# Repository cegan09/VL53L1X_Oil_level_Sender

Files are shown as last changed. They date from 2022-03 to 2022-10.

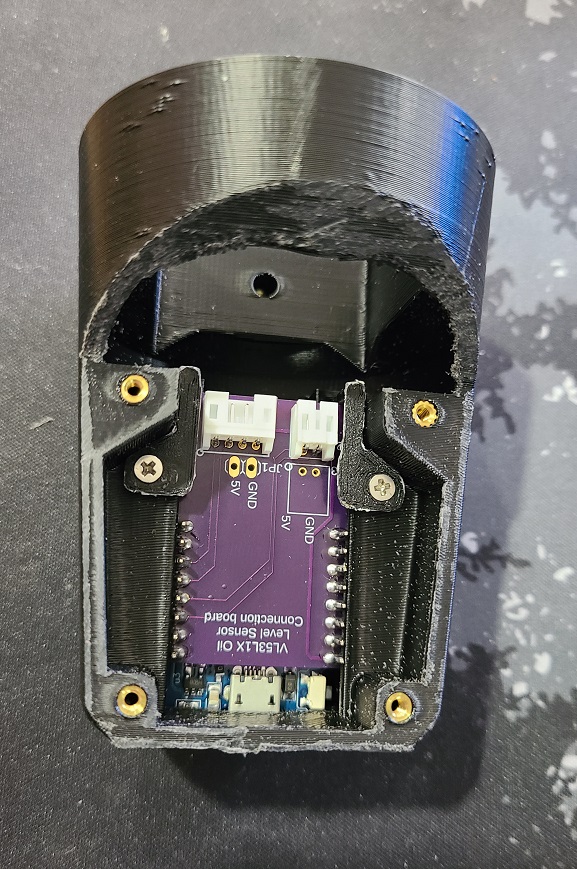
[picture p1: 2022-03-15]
pictures/Board Installed.jpg

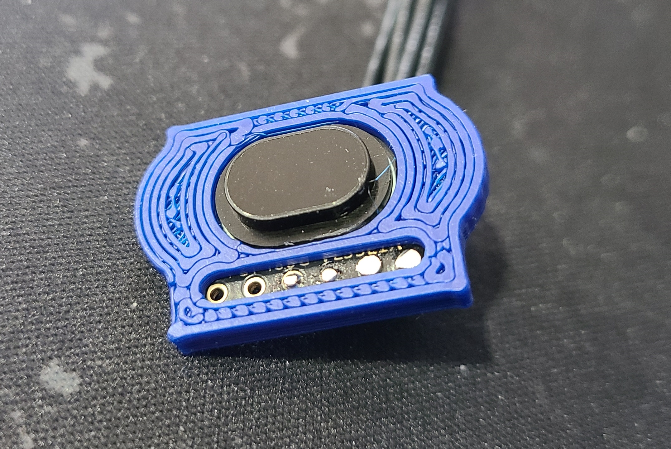
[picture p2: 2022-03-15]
pictures/Wire Test Fit.jpg

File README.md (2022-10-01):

# VL53L1X_Oil_level_Sender
DIY Home Heating Oil Level Sender

## Updates
Added configuration for ESPHome in addition to custom arduino code

## Open bugs
Occasionally I will see the device hang up. Logs show that the sensor reading is timing out. Rebooting the device works to correct this, but I haven't sorted the underlying cause yet. If you are using the ESPHome setup you can configure an automation to reboot the device when a reading of 0 comes through. 

## Warnings
This device probably voids some warrantees, will make your heating oil companies mad, and nullify your home insurance. Maybe, I'm not a lawyer. Just know that installing a DIY device on your heating oil tank probably will get some eyebrows raised if anything goes wrong. Get your tank inspected regularly, do not install if you are not comfortable doing it yourself. I am not responsible for anything that goes wrong on your end. 

There are commercial devices you can buy to perform the same function as this device that are certified and approved. If you have any hesitation to a DIY solution, go buy one of those instead. 

#### Safety
Heating oil tanks undergo some large pressures during filling and there are some safety items that you do not want to interfere with. 
1. Most commercial indoor basement tanks in North America use a whistle to tell the truck driver when to stop filling with oil. This device relies on there being no open air vents other than the single vent pipe that exists next to the fill pipe. This means your sensor needs to be sealed and air tight. This requires filling the plug that is used with potting or other appropriate epoxy. 
2. Leaks. Heating oil leaks are expensive to clean up and dangerous. Your sensor needs to be built into the correct plug, and then installed with the correct thread sealant and tightened appropriately. If you do not know how to do this, consult someone that does. 
3. Pressure. Heating oil tanks are rated to 5-7psi, which sounds low, but results in a huge force on the tank walls. Look up hoop stress if you want to know more. In a tank the size of your heating oil tank 5psi can exert hundreds of pounds of force on the shell of the tank. However, at the cap we're using, because the surface area is small, the forces on the actual device are small. If you keep the hole you drill in the plug small then potting compound or epoxy will have no problem with the forces that exist during filling. 
4. Electrical shorts and sparks. Home heating oil is thankfully not as volatile as other fuels, but you still absolutely do not want to be putting any kind of spark inside your tank. Any electrical device is a spark risk. Even if the sensor is running at 3.3v there are always surge risks from outside factors such as lightning strikes. This is why the design used here isolates and embeds all electronics in potting material. There should be no exposed path for any circuitry to be exposed to the atmosphere inside the tank. 

#### Device
With all those warnings out of the way, onto the device. Very simply this is nothing more than a Time of Flight distance sensor and a wifi connected microcontroller. The time of flight sensor measures the distance to the top of the oil level, and the micro controller does something with that data. In my case I'm simply pushing the distance off to a Node Red flow in its raw reading format. However, you can do all levels of data analysis on the microcontroller itself. ESP devices are more than capable of hosting a simple web page to display data. 

The oil level sender is effectively two parts. Part 1 is the sensor embedded in a standard off the shelf Black Iron plug. Part 2 is the microcontroller and housing. 

##### Parts List
Required:
1.	VL53L1X Sensor. There are several versions of the VL53 sensor, specifically this design uses the L1X version. Make sure you buy one with a cover. There are two common versions sold, part files are provided for each

Cover 1
Cover 2

2.	2” Black Iron Plug. These can be found at most hardware stores, once example:
https://www.homedepot.com/p/STZ-2-in-Black-Iron-Plug-310-P-2/202337741
3.	Isolation Plate. This can be made by hand, or ordered. The dxf file is included and can be sent to a service such as Send Cut Send. Alternately you can use it as a template to cut out by hand. Recommend the plate be made from regular or stainless steel, roughly 0.06” thick. 
4.	Sensor Spacer. STL files included to be printed or sent to a service. 
5.	ESP8266 Microcontroller. I use the D1 mini, but almost any version can be used, just make sure to check your wiring against the code pin definitions. 
6.	Wire. Recommend something between 26 and 22 gauge. 
7.	Potting material. The best option here is an electrically isolating potting material such as MG Chemicals - 832HD. Generic dispensing guns are available all over places like amazon. 

Optional:
1.	3d Printed enclosure. I’ve provided a few different STL files for different enclosures. You’re more than welcome to design your own or leave the microcontroller dangling on top of your tank if that’s your style. 
2.	D1 Mini Carrier board. This is the board I designed to clean up my installation. It’s certainly not required, but I have provided the board files if you want to send them to your favorite board house. Alternatively, they can be ordered straight from oshpark:
https://oshpark.com/shared_projects/pPlbGjjf
There is a BOM for this board provided in the documentation. 

##### Sensor and Plug
You should use a real metal plug bought from your local hardware store. Do not use plastic, do not 3d print something, go buy the right part, they only cost a couple dollars. In this plug drill a hole through the top that is roughly 1/4inch diameter. Feel free to do a better job centering the hole than I did.  



Prepping the sensor. First print out the spacer. This is used to make the carrier board sit flat on our isolation plate and keeps the soldered wires from shorting on the isolation plate. If the sensor cover did not come pre-installed fit it now, then test fit everything into the printed spacer. 

Sensor Test Fit

Next wire up the sensor. These can be run with or without the Interrupt and Shutdown pins. If you're trying to run multiple sensors these pins are not optional, but this device uses only one. It doesn't hurt to wire all pins and run them just in case, since you can't get at the sensor after potting. I have opted to only wire the SCL,SDA,3v3, and GND wires in these pictures. 

Sensor WIred

Fit the sensor into the spacer again and make sure the wire stubs sit recessed. Use a small file to take them down if required. You do NOT want these to touch and short out on the isolation plate. 

Wire Test Fit

If you are opting to make your own isolation plate, cut out the isolation plate. This really should be made from metal for its chemical resistance. The outer shape does not need to be perfect, but the cutout around the sensor should be a close fit. Take your time with a small file and get it close.

Isolation Plate

When your parts are ready, first glue the sensor into the spacer. I used a little CCA glue just to hold it in place until the potting compound sets. 

Sensor Glued in

The potting epoxy likes to seep through any open gap. It’s wise to seal up around the sensor before we install the plate into the plug. The best approach I’ve found is to use hot melt glue to seal the front of the sensor cover and make a dam around the spacer. These keeps the potting material from leaking onto the front of the sensor cover or dripping off the edge of the isolation plate. So first build up a ring of hot melt glue around the place where the sensor will be placed.

Glue Dam

Next place a small amount of potting epoxy on the isolation plate to seal between the plate and sensor spacer/PCB.

First Potting Layer

Place the sensor on the plate being careful not to get any potting material on the sensor cover. Then hold it in place and add hot melt glue to the front surface. This both holds the sensor in place and stops potting material from leaking out  around the cover. 

Sensor Dam

Add a thin layer of potting material to the dammed area. The goal is not to fill the whole area, just add enough to coat everything and allow it to seal up. 

First Light Potting Fill

Once the potting material is fully cured (minimum 12 hours), remove all the hot melt glue. 
Now we need to fully pot the sensor into the cap. First fully clean the metal plug. Often they are shipped with a thin layer of oil coating them to stop corrosion. You want to fully remove this from the inside so that the potting material and hot melt glue will stick. 

Pass the wiring through the cap, and populate the connectors. I strongly suggest testing this now before you pot everything and lose the ability to diagnose a miswired connector. 



Use more hot melt glue to hold the isolation plate into the cap and seal up the gap between the two. This will keep the potting material from leaking through and making a mess. 



Now it's time to inject the potting compound into the back of the sensor through the hole we drilled for wires. Take your time and inject the compound allowing it to flow and settle a little bit at a time. You want this cavity completely filled. Allow this to completely cure. 




Once everything is cured remove the hot melt glue we applied earlier. 

You can now optionally add a chemically resistant epoxy to the joint between the isolation plate and plug. This shouldn’t be strictly necessary, but it’s not a bad idea to add.  

You should now have your completed sensor plug assembly. 

##### Microcontroller and Enclosure
This part is flexible. You can follow my version, or you can really attach any microcontroller you prefer and enclose in any way you want. If you are using my design, I have a few options. I've designed this around an ESP8266 D1 Mini. The ESP32 is newer and fancier, but we really don't need the increased power of the newer device. You can hand wire everything, or you can order the cheap connection PCB I have designed and linked on oshpark. All this board does is make wiring the device easier, it's not necessary if you're comfortable hand wiring things. 

For enclosures I have three versions. Two are based around using my connector board, the other is just a bare shell that you can use for fitting your own wiring and microcontroller into. The two based around my design allow you to either expose the USB connector on the D1 mini or install a DC power jack.

For any of the enclosures I recommend printing in either PETG or ABS/ASA. I suggest minimum 3 shells, 4 is better to make sure there is enough material around the threaded inserts. I use brass heat set inserts for all fasteners. 

Wiring is straight forward. Whether you use my carrier board or wire it all by hand the connections are the same. If you do use my carrier board you can get away with only wiring up 3.3V, ground, SCL, and SDA, though adding the Shutdown and interrupt wires may let you write more complicated programs. If you do use my carrier board you have the option to wire power to a 2mm pitch JST connector, or just solder wires directly to the board at JP1. If you're exposing the USB connector then you can skip either of those as power will come from the USB. 

Carrier Board 1
Carrier Board 2
Board Installed

#### Installation
Installing the device is straightforward. You will first need to remove one of the extra plugs in the top of your tank. I recommend picking the one furthest from the fill pipe to avoid splashing when the tank is being filled. Before threading in the device, make sure to apply the appropriate pipe dope compound to the threads to make sure it seals and prevent the threads corroding. 

Thread the plug in by hand to make sure it does not cross thread, then tighten down fully. 

Make the connections to the microcontroller, then place the enclosure over the plug and secure with the two set screws to hold it onto the plug. 

Lastly attach the cover and plug in. 

#### Firmware
I have provided my Arduino sketch and some basic node red flows if you wish to copy my setup exactly. I won't go in depth on how to setup node red and MQTT, there are plenty of better tutorials out there than any I could write. The basic overview of my firmware is as follows. 
The microcontroller samples the distance to the oil level 5 times, then averages those readings in an attempt to rule out some measurement error. This reading is then published over MQTT. Then the device waits a set amount of time and repeats. That's basically it. I'm doing all the data analysis off device in the node red flow. The sparkfun VL53X1L library has a lot of features that could be used to calibrate offsets and then do all the math right on the microcontroller skipping the node red portion all together. I choose to do it off device because I already have a node red setup that is doing weather fetching and other data analysis, so it made sense to crunch numbers there. 

I've included a very basic node red flow that will capture the incoming readings, store them, and do some basic plotting and usage calculations.

Oil Data

I've done some commenting of my code, but it needs more. I'll get around to uploading some updated files soon. 

If you want to use this device with home assistant I have now added some ESPHome code to get you started. This does require adding a custom library to your esphome setup. 
https://github.com/jardous/tof_vl53l1x
I removed the wireless, OTA, and encryption info from the example .yaml file.

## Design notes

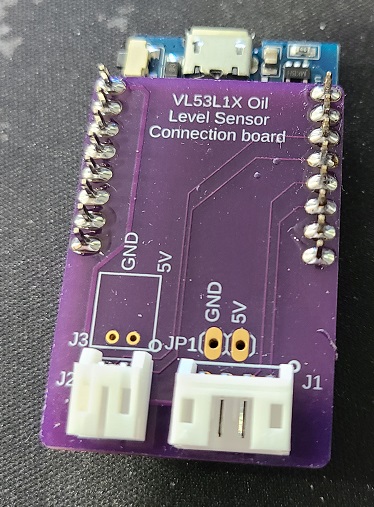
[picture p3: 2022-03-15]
pictures/Carrier Board 1.jpg

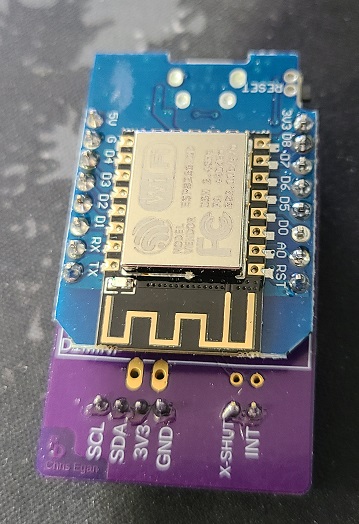
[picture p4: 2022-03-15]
pictures/Carrier Board 2.jpg

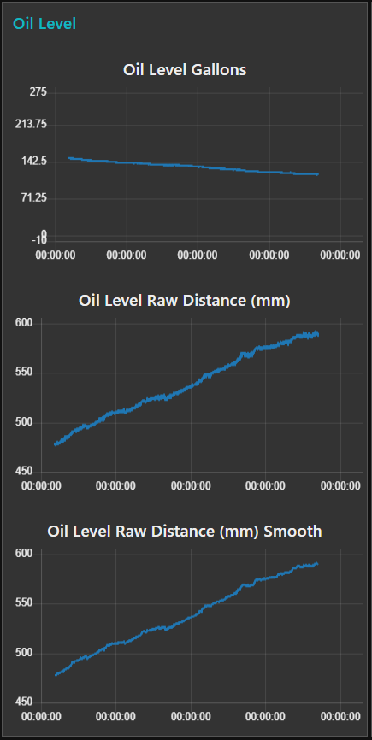
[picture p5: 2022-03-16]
pictures/Oil Data.PNG

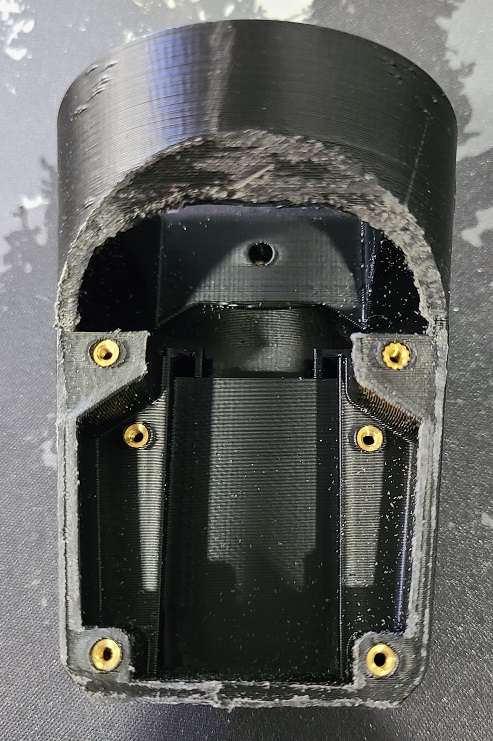
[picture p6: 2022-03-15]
pictures/2-56 inserts.jpg

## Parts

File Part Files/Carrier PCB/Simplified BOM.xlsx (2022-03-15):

PCB Components
Qty | Device | Parts | Description | MANUFACTURER | MPN | Notes
2 | 1X2PIN-GPIO | J2, J3 | 2 pin shrouded 2mm Connector | JST | S2B-PH-K-S(LF)(SN) | Both Optional depending on configuration
1 | 1X4PIN-GPIO | J1 | 4 pin shrouded Connector | Adam Tech | 2SH-C-04-TR
1 | D1_MINI | D1MINI | D1 Mini Microcontroller |  |  | Many sources, so no specific part number provided
1 | PINHD-1X2 | JP1 | 2 Pin 0.1" header |  |  | Optional, normally just solder wires to the through holes
Wiring
 | Pre-terminated Leads |  | JST Pre-Crimped wires for 2mm connectors | JST | 455-3083-ND
 | 4 position connector body |  |  | Adam Tech | 2CH-C-04
 | 2 position connector body |  |  | JST | PHR-2

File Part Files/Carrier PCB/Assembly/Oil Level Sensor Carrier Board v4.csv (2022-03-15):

Qty | Value | Device | Package | Parts | Description | CATEGORY | DESCRIPTION | MANUFACTURER | MPN | OPERATING_TEMP | PART_STATUS | ROHS_COMPLIANT | SERIES | SUB-CATEGORY | THERMALLOSS | TYPE
2 | 1X2PIN-GPIO | 1X2PIN-GPIO | S2B-PH-K-S | J2, J3 |  |  |  | JST | S2B-PH-K-S(LF)(SN)
1 | 1X4PIN-GPIO-RA-JST-SHROUDED | 1X4PIN-GPIO-RA-JST-SHROUDED | 1X4PIN-S4B-PH-K-S | J1 |  |  |  | Adam's Tech | 2SH-C-04-TR
1 | D1_MINI | D1_MINI | D1_MINI | D1MINI
1 | PINHD-1X2 | PINHD-1X2 | 1X02 | JP1 | PIN HEADER | CONNECTOR |  |  |  |  |  |  |  | PIN-HEADER

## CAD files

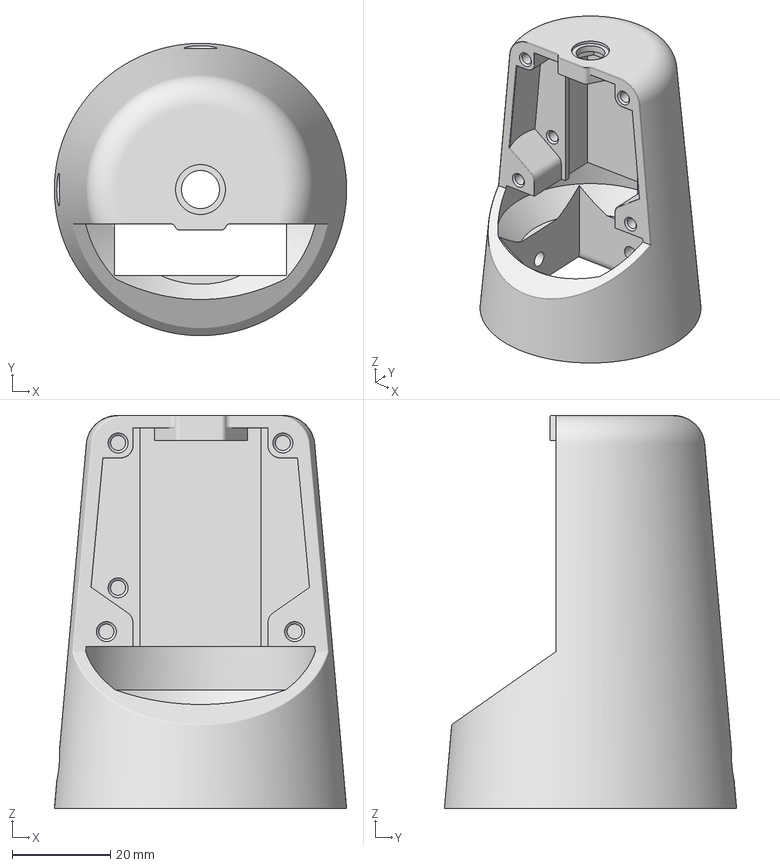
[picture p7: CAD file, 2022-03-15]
Part Files/Main Enclosures/Main Enclosure - Carrier Board - DC Jack.3mf
59.4 x 59.4 x 79.9 mm

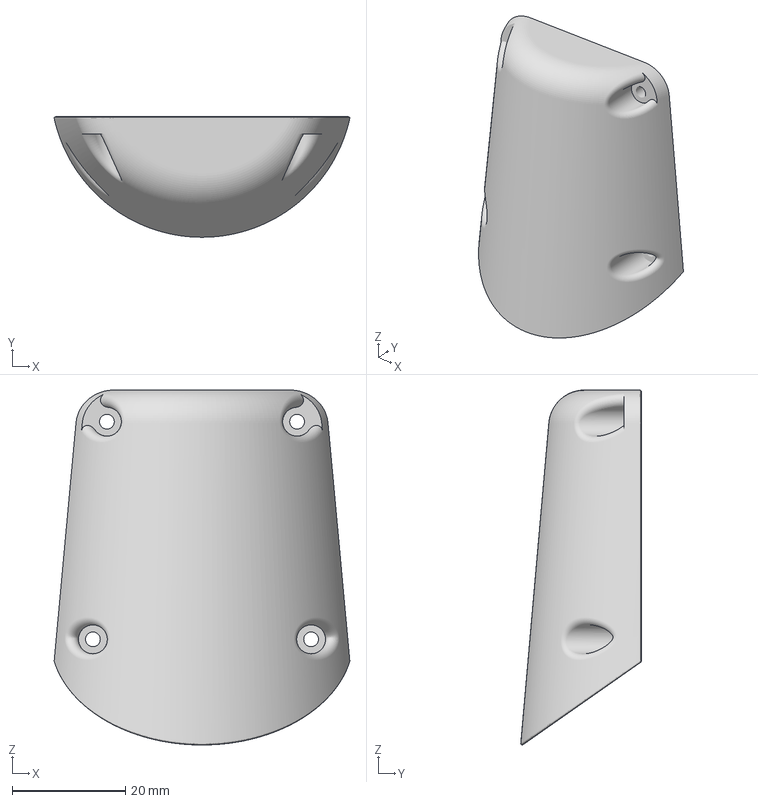
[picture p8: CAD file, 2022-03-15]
Part Files/Main Enclosures/Main Enclosure - carrier board - USB exposed.3mf
52.1 x 21.2 x 62.6 mm

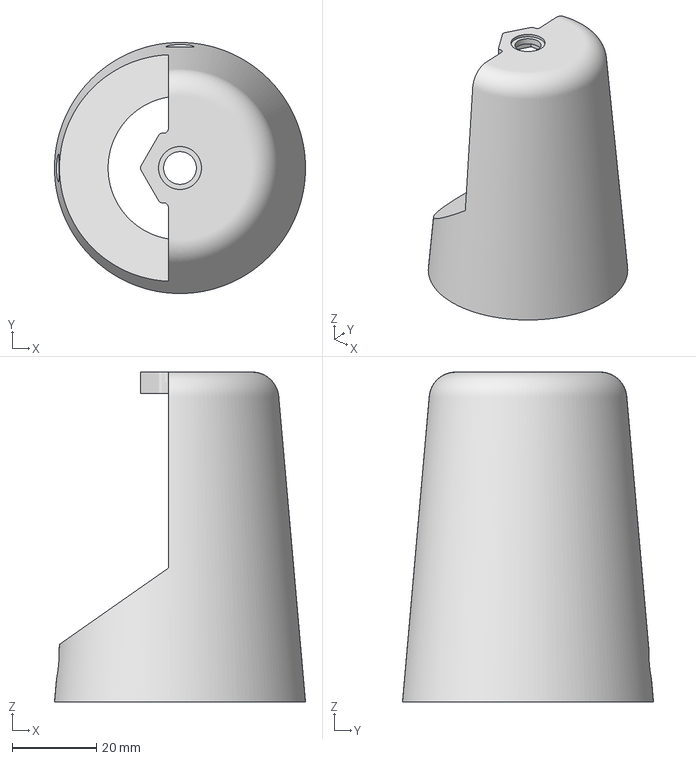
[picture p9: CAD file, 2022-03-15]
Part Files/Main Enclosures/Main Enclosure - D1 Mini only - DC Jack.3mf
59.4 x 59.4 x 78.1 mm

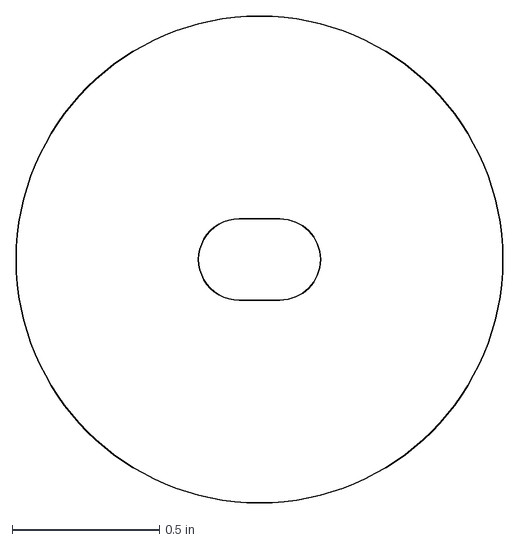
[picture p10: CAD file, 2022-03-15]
Part Files/Isolation Plate/Isolation Plate - Sensor 2.dxf
1.65 x 1.65 in

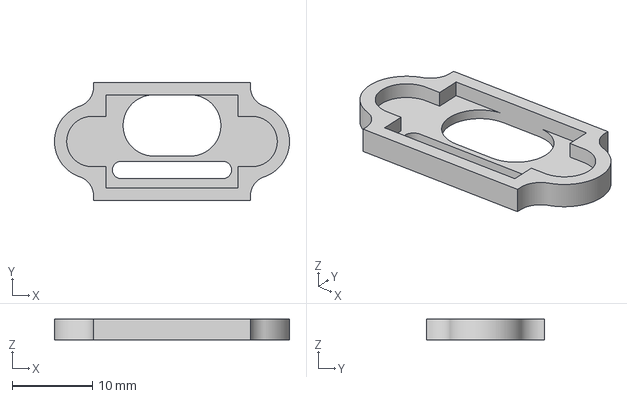
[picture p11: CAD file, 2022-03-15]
Part Files/Sensor Spacers/Spacer - Sensor 1.3mf
29.3 x 14.7 x 2.57 mm

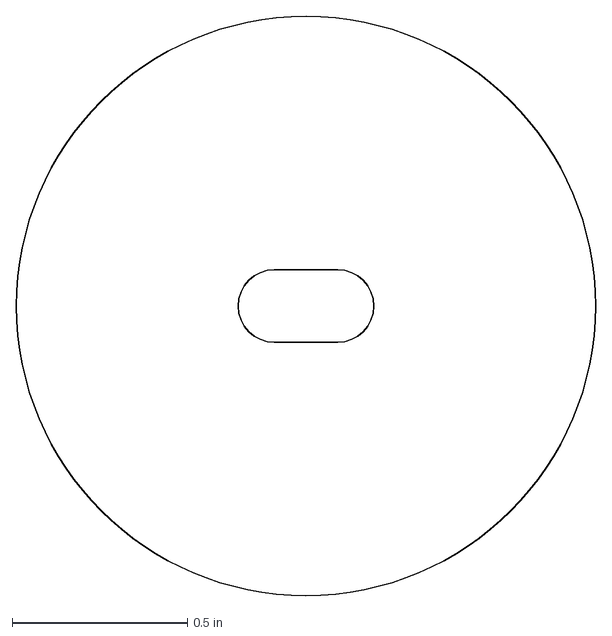
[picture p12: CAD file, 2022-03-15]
Part Files/Isolation Plate/Isolation Plate - Sensor 1.dxf
1.65 x 1.65 in

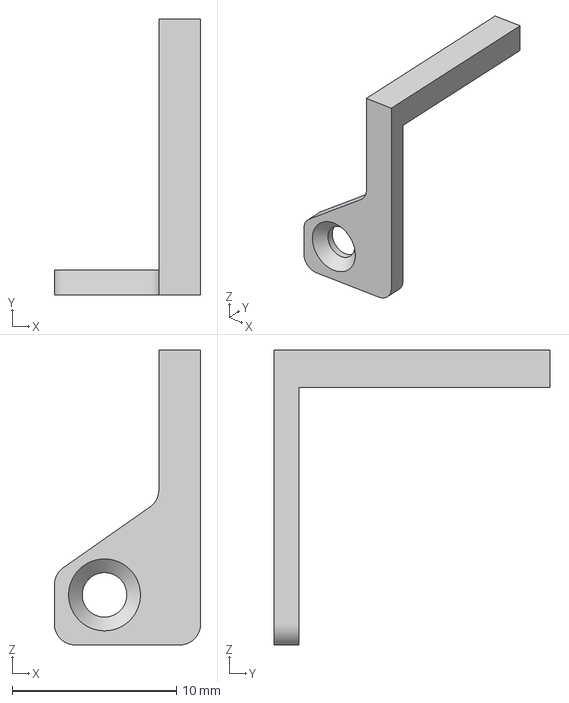
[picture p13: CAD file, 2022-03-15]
Part Files/Main Enclosures/Board holder - USB exposed (mirror).3mf
8.89 x 16.8 x 17.9 mm

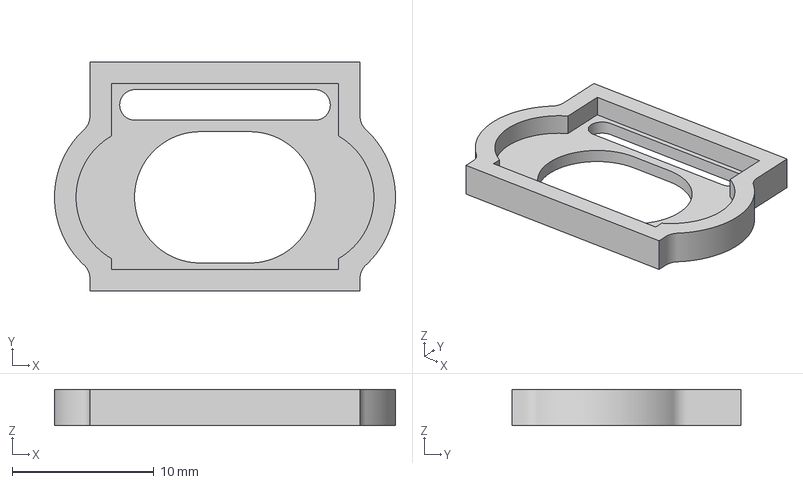
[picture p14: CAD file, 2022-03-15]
Part Files/Sensor Spacers/Spacer - Sensor 2.3mf
24.1 x 16.2 x 2.57 mm

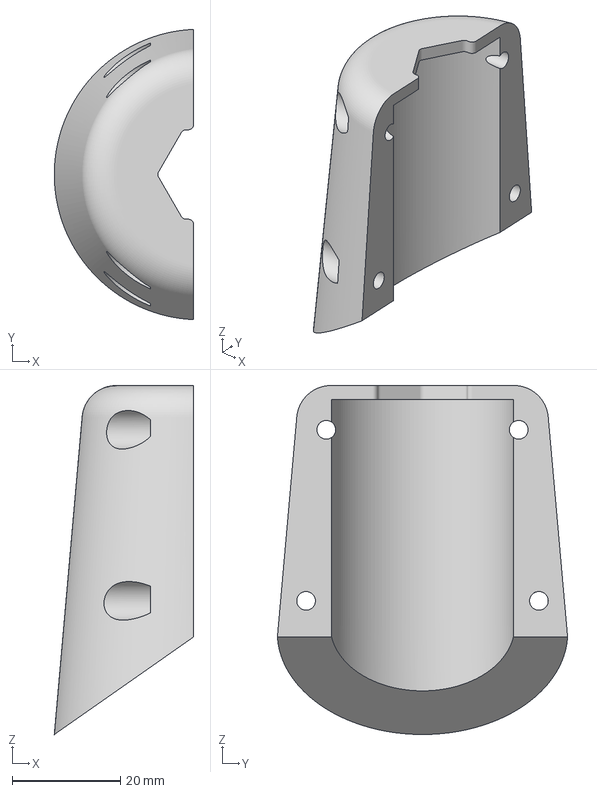
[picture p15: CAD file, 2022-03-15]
Part Files/Main Enclosures/Enclosure Cover - D1 Mini Only - DC Jack.3mf
25.8 x 53.6 x 64.5 mm

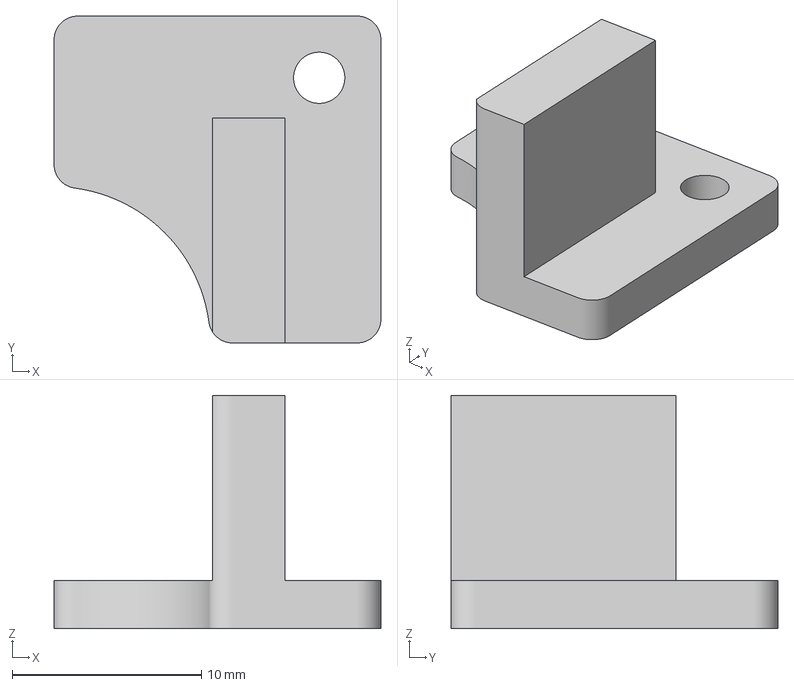
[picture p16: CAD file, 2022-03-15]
Part Files/Main Enclosures/Board Holder - D1 Mini Only.3mf
17.3 x 17.3 x 12.3 mm

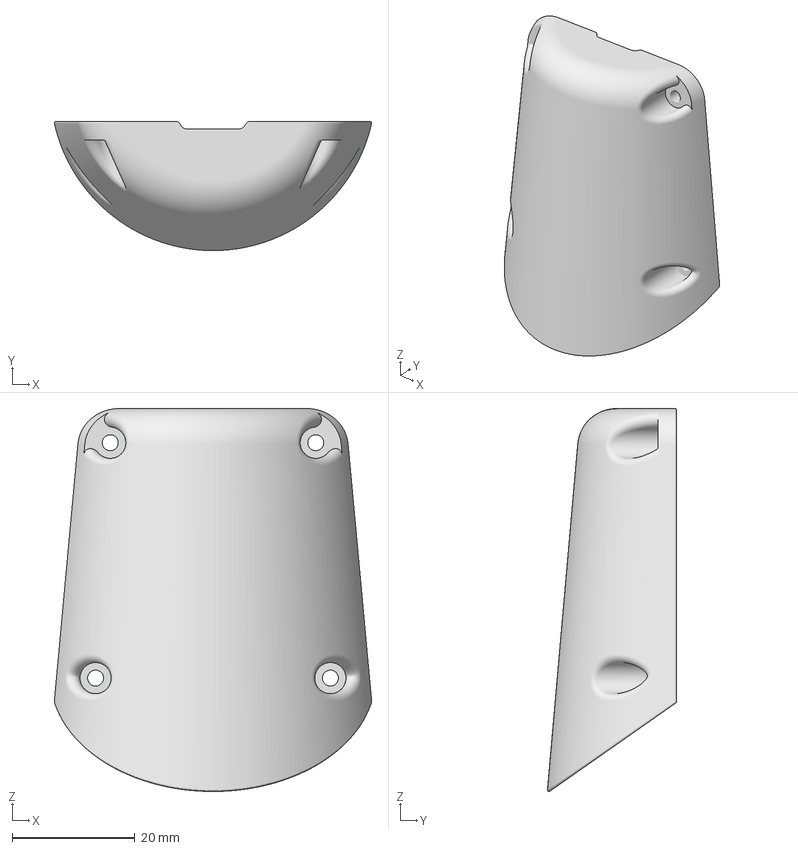
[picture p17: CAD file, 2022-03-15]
Part Files/Main Enclosures/Enclosure Cover - Carrier Board - DC Jack.3mf
51.7 x 21.1 x 62.4 mm

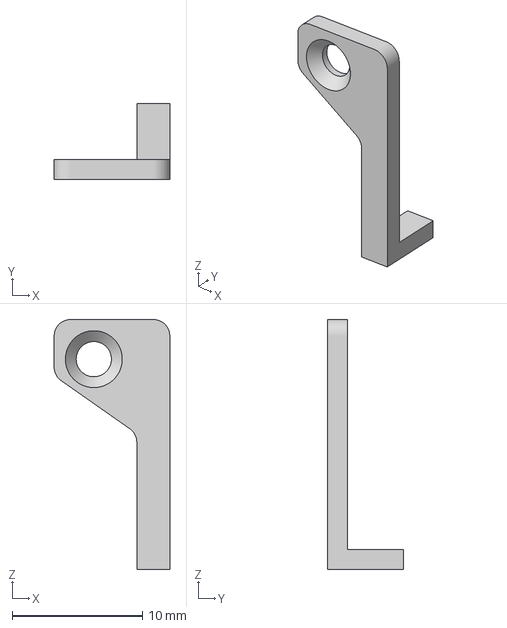
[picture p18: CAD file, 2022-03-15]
Part Files/Main Enclosures/Board Holder - DC Jack.3mf
8.89 x 5.84 x 19.2 mm

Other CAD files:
Part Files/Main Enclosures/Enclosure Cover - Carrier Board - USB Exposed.3mf
Part Files/Main Enclosures/Board holder - USB exposed.3mf

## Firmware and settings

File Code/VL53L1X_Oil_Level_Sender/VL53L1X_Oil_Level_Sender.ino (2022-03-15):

#include <ComponentObject.h>
#include <RangeSensor.h>
#include <SparkFun_VL53L1X.h>
#include <vl53l1x_class.h>
#include <vl53l1_error_codes.h>
#include <ESP8266WiFi.h>
#include <PubSubClient.h>
#include <Wire.h>
#include "SparkFun_VL53L1X.h"
#include <ESP8266mDNS.h>
#include <WiFiUdp.h>
#include <ArduinoOTA.h>
#include "arduino_secrets.h"

/*
 * You should define your wifi info and OTA Password in a secrets file. Add a tab to this sketch
 * and name it "arduino_secrets.h". Use the format:
 * #ifndef STASSID
 * #define SECRET_STASSID ""               //set SSID here
 * #define SECRET_STAPSK  ""   //set network password here
 * #endif
 * 
 * #define SECRET_OTAPASSWORD ""  //set OTA Password here
 */
const char* ssid = SECRET_STASSID;
const char* password = SECRET_STAPSK;

String OTA = SECRET_OTAPASSWORD;

//Optional interrupt and shutdown pins.
#define SHUTDOWN_PIN 0
#define INTERRUPT_PIN 2

/*
 * Set your MQTT topics here. If you leave these as I have defined them
 * everything will work with Node Red as written. If you change anything 
 * you will need to update Node Red as well. 
 */
#define dist_topic "sensors/oil/distance"   //raw distance reading
#define avg_topic "sensors/oil/avgdistance" //average distance reading
#define alive_topic "sensors/alive/oil"     //Heartbeat topic for detecting when sensors go offline

//Variables that I use throughout the sketch
int period = 300000;                //the length of time between sampling in milliseconds
int samplerate = 250;               //Time between each distance read used to generate the average
int alive = 60000;                  //Time between alive signals
int boot = 0;                       //Used to indicate boot to the main loop
unsigned long time_now = 0;         //Used for calculating if it's time for another reading
unsigned long sample_now = 0;       //Used for calculating if it's time for another sample
unsigned long alive_now = 0;        //Used for calculating if it's time to send the heartbead signal


String dist_str;     //string variable for storing distance readings
char dist[50];       //another variable for putting the readings into the right format for MQTT
int dist_array[6];  //array for storing each sample during a reading. 
int sample = 0;     //variable used for counting which sample is being taken


// this sets up the connection to the MQTT broker. So you need that setup first. 
const char* mqtt_server = "192.168.x.x";    //Enter the IP address of your broker here. You should make sure this is a static IP
const char* mqttclient = "OIL";           //Name the ESP device here, each ESP needs a distinct name.

// Initializes the espClient. You should change the espClient name if you have multiple ESPs running in your network
WiFiClient OIL;           //I make this the same as the mqttclient above
PubSubClient client(OIL); //I make this the same as the mqttclient above
String clientId = "OIL";  //I make this the same as the mqttclient above

SFEVL53L1X distanceSensor;
//Uncomment the following line to use the optional shutdown and interrupt pins.
//SFEVL53L1X distanceSensor(Wire, SHUTDOWN_PIN, INTERRUPT_PIN);

void setup() {
  Wire.begin();
  
  Serial.begin(115200);
  setup_wifi();         //runs the start wifi block, see further down

//start of OTA setup
  // Port defaults to 8266
  // ArduinoOTA.setPort(8266);

  // Hostname defaults to esp8266-[ChipID]
  ArduinoOTA.setHostname("OIL");  //recomend making this the same as above client names

  // No authentication by default
  ArduinoOTA.setPassword(OTA.c_str());

  // Password can be set with it's md5 value as well
  // MD5(admin) = 21232f297a57a5a743894a0e4a801fc3
  // ArduinoOTA.setPasswordHash("21232f297a57a5a743894a0e4a801fc3");

  ArduinoOTA.onStart([]() {
    String type;
    if (ArduinoOTA.getCommand() == U_FLASH) {
      type = "sketch";
    } else { // U_FS
      type = "filesystem";
    }

    // NOTE: if updating FS this would be the place to unmount FS using FS.end()
    Serial.println("Start updating " + type);
  });
  ArduinoOTA.onEnd([]() {
    Serial.println("\nEnd");
  });
  ArduinoOTA.onProgress([](unsigned int progress, unsigned int total) {
    Serial.printf("Progress: %u%%\r", (progress / (total / 100)));
  });
  ArduinoOTA.onError([](ota_error_t error) {
    Serial.printf("Error[%u]: ", error);
    if (error == OTA_AUTH_ERROR) {
      Serial.println("Auth Failed");
    } else if (error == OTA_BEGIN_ERROR) {
      Serial.println("Begin Failed");
    } else if (error == OTA_CONNECT_ERROR) {
      Serial.println("Connect Failed");
    } else if (error == OTA_RECEIVE_ERROR) {
      Serial.println("Receive Failed");
    } else if (error == OTA_END_ERROR) {
      Serial.println("End Failed");
    }
  });
  ArduinoOTA.begin();
  Serial.println("Ready");
  Serial.print("IP address: ");
  Serial.println(WiFi.localIP());
//end OTA setup    

  client.setServer(mqtt_server, 1883);  //starts the mqtt setup process
  client.setCallback(callback);
  Serial.println("setup");  //debugging line.

  if (distanceSensor.begin() != 0) //Begin returns 0 on a good init
  {
    Serial.println("Sensor failed to begin. Please check wiring. Freezing...");
    while (1)
      ;
  }
  Serial.println("Sensor online!");
  

  time_now = millis();    //sets the current time variable to the current milliseconds reading
  //sample_now = millis();  //sets the sample time variable to the current milliseconds reading
}

void loop() {

  if (!client.connected()) {    //reconnects the ESP if it becomes dissconnected
    reconnect();
  }

  if (boot == 0){   //If this is the first time the loop runs, send out an initial hello heartbeat
    client.publish(alive_topic, "hello");
    boot = 1;
  }

  if (sample > 4){     
    Serial.print("5 readings reached. Average = ");
    sample = 0;
    //disregard first reading, average the rest
    long dist_avg = (dist_array[1] + dist_array[2] + dist_array[3] + dist_array[4])/4;
    Serial.println(dist_avg);
    dist_str = String(dist_avg);
    dist_str.toCharArray(dist, dist_str.length() + 1);
    client.publish(avg_topic, dist);
    for (int i = 0; i < 7; i++){
      dist_array[i] = 0;
    }
    time_now = millis();    //reset the time now variable so the program will wait for another period of time
  }

  if (millis() > time_now + period){        //compares the current time to the period defined above. once that period is reached it runs the reading again
    if ( millis() > sample_now + samplerate){
      sample = sample + 1;
      sample_now = millis();
      measure();
    }
    
  }
  client.loop();
  ArduinoOTA.handle();

  if (millis() > alive_now + alive){    //if it's time to send a heartbeat message, send "1"
    client.publish(alive_topic, "1");
    alive_now = millis();
  }
}

//Distance measure function
void measure(){
  distanceSensor.startRanging(); //Write configuration bytes to initiate measurement
  while (!distanceSensor.checkForDataReady())
  {
    delay(1);
  }
  int distance = distanceSensor.getDistance(); //Get the result of the measurement from the sensor
  distanceSensor.clearInterrupt();
  distanceSensor.stopRanging();
  dist_array[sample] = distance;
  Serial.print("sample = ");
  Serial.println(sample);
  Serial.print("stored distance: ");
  Serial.println(dist_array[sample]);
}


//This is what connects you to the wifi network. you shouldn't have to touch this. There are serial debugging lines included
void setup_wifi() {
  delay(10);
  // We start by connecting to a WiFi network
  Serial.println();
  Serial.print("Connecting to ");
  WiFi.mode(WIFI_STA);
  Serial.println(ssid);
  WiFi.begin(ssid, password);
  while (WiFi.status() != WL_CONNECTED) {
    delay(500);
    Serial.print(".");
  }
  Serial.println("");
  Serial.print("WiFi connected - ESP IP address: ");
  Serial.println(WiFi.localIP());
}


// This functions reconnects your ESP8266 to your MQTT broker
// Change the function below if you want to subscribe to more topics with your ESP8266 
void reconnect() {
  // Loop until we're reconnected
  while (!client.connected()) {
    Serial.print("Attempting MQTT connection...");
    // Attempt to connect
    /*
     YOU MIGHT NEED TO CHANGE THIS LINE, IF YOU'RE HAVING PROBLEMS WITH MQTT MULTIPLE CONNECTIONS
     To change the ESP device ID, you will have to give a new name to the ESP8266.
     Here's how it looks:
       if (client.connect("ESP8266Client")) {
     You can do it like this:
       if (client.connect("ESP1_Office")) {
     Then, for the other ESP:
       if (client.connect("ESP2_Garage")) {
      That should solve your MQTT multiple connections problem
    */
    if (client.connect(clientId.c_str())) { 
      Serial.println("connected");  
      
      // Subscribe or resubscribe to a topic
      // You can subscribe to more topics if you want. 
      // For my setup the ESP doesn't really need to listen at all, but I have this setup so I can "ping" the senors periodically if needed
      client.subscribe("sensors/status");
    } else {
      Serial.print("failed, rc=");
      Serial.print(client.state());
      Serial.println(" try again in 5 seconds");
      // Wait 5 seconds before retrying
      delay(5000);
    }
  }
}

// This functions is executed when some device publishes a message to a topic that your ESP8266 is subscribed to
// Change the function below to add logic to your program, so when a device publishes a message to a topic that 
// your ESP8266 is subscribed you can actually do something
// In this case it's not important to do anything since the ESP is only broadcasting data, nothing else
void callback(String topic, byte* message, unsigned int length) {
  Serial.print("Message arrived on topic: ");
  Serial.print(topic);
  Serial.print(". Message: ");
  String messageTemp;
  
  for (int i = 0; i < length; i++) {
    Serial.print((char)message[i]);
    messageTemp += (char)message[i];
  }
  Serial.println();

  // If a message is received on the topic sensor/status, respond with connected
  if(topic=="sensors/status"){
      Serial.print("call for status");
      if(messageTemp == "check"){
        client.publish(alive_topic, "hello");    
      }
  }
  Serial.println();
}

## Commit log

2022-03-15 Hardware Files Added
    [Board Holder - D1 Mini Only.3mf, Board Holder - DC Jack.3mf, Board holder - USB exposed (mirror).3mf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]
2022-03-15 Added node Red Flows
